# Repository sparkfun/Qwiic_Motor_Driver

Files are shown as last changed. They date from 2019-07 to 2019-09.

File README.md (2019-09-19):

SparkFun Qwiic_Motor_Driver
========================================

SparkFun Qwiic Motor Driver

[*SparkFun Qwiic Motor Driver (15451)*](https://www.sparkfun.com/products/15451)

The SparkFun Qwiic Motor Driver takes all the great features of the Serial Controlled Motor Driver (SCMD) and miniaturizes them, adding [Qwiic](https://www.sparkfun.com/qwiic) ports for plug and play functionality. Boasting the same 4245 PSOC and 2-channel motor ports as the SCMD, the SparkFun Qwiic Motor Driver is designed to communicate over I<sup>2</sup>C to make setting up your next robotic project as fast and easy as possible! Utilizing our handy Qwiic system, no soldering is required to connect it to the rest of your system. 

With 1.2A steady state drive per channel (1.5A peak) and 127 levels of DC drive strength, this little Qwiic board is perfect for your small DC motor driver needs. Since the Qwiic Motor Driver is a 3.3V logic device, you'll need to use a logic level converter to interface to 5V.

Repository Contents
-------------------

* **/Hardware** - Eagle design files (.brd, .sch)

Documentation
--------------
* **[Serial Controlled Motor Driver Library](https://github.com/sparkfun/SparkFun_Serial_Controlled_Motor_Driver_Arduino_Library)** - Arduino library for the Qwiic Motor Driver.
* **[Hookup Guide](https://learn.sparkfun.com/tutorials/hookup-guide-for-the-qwiic-motor-driver)** - Basic hookup guide for the Qwiic Motor Driver.

License Information
-------------------

This product is _**open source**_! 

Please review the LICENSE.md file for license information. 

If you have any questions or concerns on licensing, please contact technical support on our [SparkFun forums](https://forum.sparkfun.com/viewforum.php?f=152).

Distributed as-is; no warranty is given.

- Your friends at SparkFun.

_<COLLABORATION CREDIT>_

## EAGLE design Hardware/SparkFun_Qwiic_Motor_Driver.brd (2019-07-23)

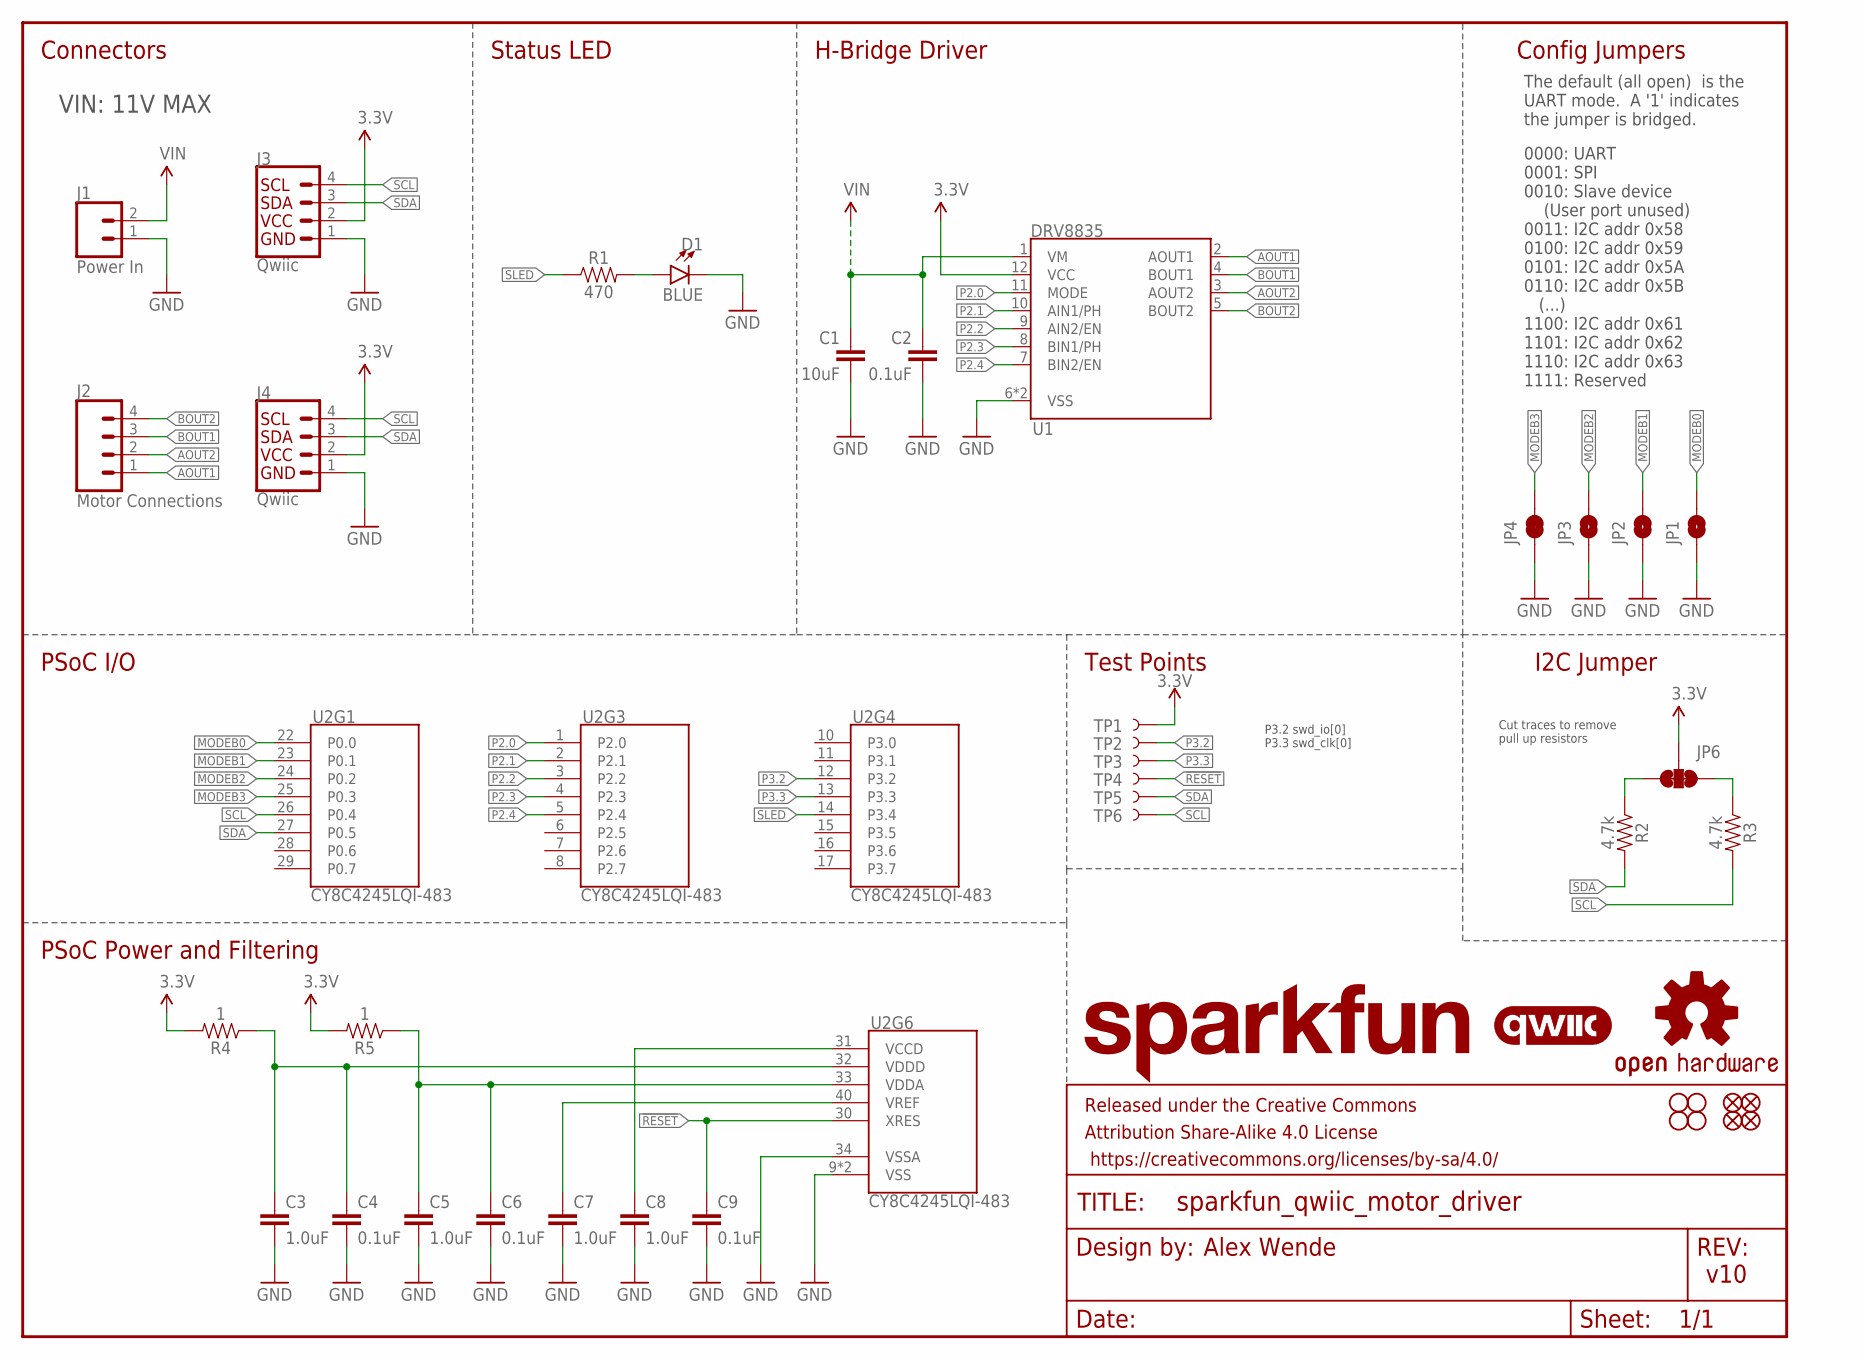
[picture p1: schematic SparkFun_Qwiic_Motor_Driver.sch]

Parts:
C1: 10uF; 0805
C2, C4, C6, C9: 0.1uF; 0402
C3, C5, C7, C8: 1.0uF; 0402
D1: BLUE; LED-0603
FD1, FD2, FD3, FD4: FIDUCIALUFIDUCIAL; FIDUCIAL-MICRO
FRAME1: FRAME-LETTER; CREATIVE_COMMONS
H1, H2, H3, H4: STAND-OFF
J1: Power In; SCREWTERMINAL-3.5MM-2
J2: Motor Connections; SCREWTERMINAL-3.5MM-4
J3, J4: Qwiic; JST04_1MM_RA
JP1, JP2, JP3: JUMPER-PAD-2; SMT-JUMPER_2_NO_NO-SILK
JP4: JUMPER-PAD-2; SMT-JUMPER_2_NC_TRACE_NO-SILK
JP6: JUMPER-SMT_3_2-NC_TRACE_NO-SILK; SMT-JUMPER_3_2-NC_TRACE_NO-SILK
LOGO2: OSHW-LOGOMINI; OSHW-LOGO-MINI
LOGO3: SFE_LOGO_NAME.1_INCH; SFE_LOGO_NAME_.1
R1: 470; 0603
R2, R3: 4.7k; 0603
R4, R5: 1; 0603
TP1, TP2, TP3, TP4, TP5, TP6: TEST-POINTTP_15TH_THRU; TP_15TH
U1: DRV8835; WSON-12
U2: CY8C4245LQI-483; QFN-40
U$1: QWIIC_LOGO_5MM; QWIIC_5MM

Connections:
3.3V: J3.2, J4.2, JP6.2, R4.2, R5.2, TP1.P$1, U1.12 (VCC)
!RESET: C9.1, TP4.P$1, U2.30 (XRES)
AOUT1: J2.1, U1.2 (AOUT1)
AOUT2: J2.2, U1.3 (AOUT2)
BOUT1: J2.3, U1.4 (BOUT1)
BOUT2: J2.4, U1.5 (BOUT2)
GND: C1.2, C2.2, C3.2, C4.2, C5.2, C6.2, C7.2, C8.2, C9.2, D1.C, J1.1, J3.1, J4.1, JP1.1, JP2.1, JP3.1, JP4.1, U1.6 (VSS), U1.PAD (VSS), U2.9 (VSS), U2.34 (VSSA), U2.EP (VSS)
MODEB0: JP1.2, U2.22 (P0.0)
MODEB1: JP2.2, U2.23 (P0.1)
MODEB2: JP3.2, U2.24 (P0.2)
MODEB3: JP4.2, U2.25 (P0.3)
unnamed: C8.1, U2.31 (VCCD)
unnamed: C5.1, C6.1, R5.1, U2.33 (VDDA)
unnamed: C7.1, U2.40 (VREF)
unnamed: D1.A, R1.2
unnamed: JP6.1, R3.1
unnamed: JP6.3, R2.1
P2.0: U1.11 (MODE), U2.1 (P2.0)
P2.1: U1.10 (AIN1/PH), U2.2 (P2.1)
P2.2: U1.9 (AIN2/EN), U2.3 (P2.2)
P2.3: U1.8 (BIN1/PH), U2.4 (P2.3)
P2.4: U1.7 (BIN2/EN), U2.5 (P2.4)
P3.2: TP2.P$1, U2.12 (P3.2)
P3.3: TP3.P$1, U2.13 (P3.3)
SCL: J3.4, J4.4, R3.2, TP6.P$1, U2.26 (P0.4)
SDA: J3.3, J4.3, R2.2, TP5.P$1, U2.27 (P0.5)
SLED: R1.1, U2.14 (P3.4)
VDDD: C3.1, C4.1, R4.1, U2.32 (VDDD)
VIN: C1.1, C2.1, J1.2, U1.1 (VM)

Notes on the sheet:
PSoC Power and Filtering
Config Jumpers
Alex Wende
PSoC I/O
v10
P3.2 swd_io[0] P3.3 swd_clk[0]
0000: UART 0001: SPI 0010: Slave device (User port unused) 0011: I2C addr 0x58 0100: I2C addr 0x59 0101: I2C addr 0x5A 0110: I2C addr 0x5B (...) 1100: I2C addr 0x61 1101: I2C addr 0x62 1110: I2C addr 0x63 1111: Reserved
The default (all open) is the UART mode. A '1' indicates the jumper is bridged.
Connectors
Status LED
H-Bridge Driver
Test Points
I2C Jumper
VIN: 11V MAX
Cut traces to remove pull up resistors

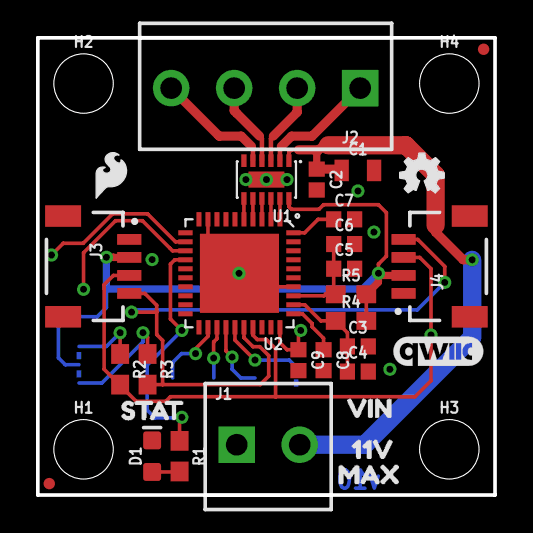
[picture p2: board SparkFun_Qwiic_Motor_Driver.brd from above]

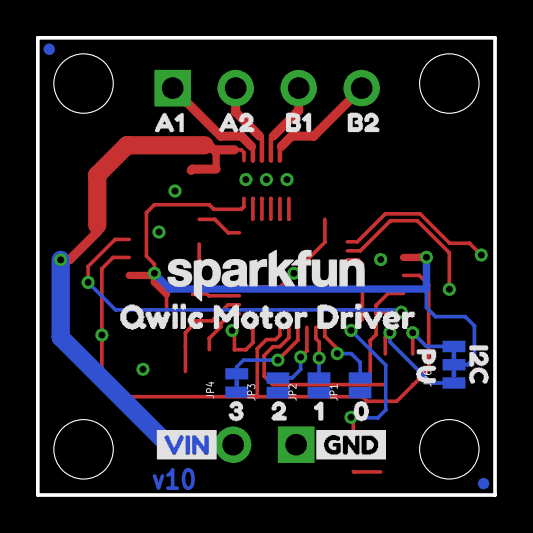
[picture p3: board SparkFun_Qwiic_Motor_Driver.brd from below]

Board: 2 copper layers, 25.4 x 25.4 mm, 62 parts (21 on the bottom side), 29 nets.

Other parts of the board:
U$2: STAT4
U$3: GND3
U$4: VIN2
U$5: 05
U$6: 16
U$7: 27
U$8: 38
U$9: A110
U$10: A211
U$11: B112
U$12: B213
U$13: 11V7
U$14: MAX8
U$15: VIN6
U$16: I2C0
U$17: PU1
U$18: QWIIC_MOTOR_DRIVER0
U$19: SFE_LOGO_FLAME_.1

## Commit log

2019-06-26 v01 Design Review Changes
    - Added I2C test points
    - Moved motor connector symbol to connection section
    - Changed status LED to blue
    - Adjusted VIN trace width
    - Added SFE flame to top side of board
    [SparkFun_Qwiic_Motor_Driver.brd, SparkFun_Qwiic_Motor_Driver.sch]
2019-07-22 v10 Update
    - Added new 4-pin screw terminal instead of 2x2-pin screw terminals
    - Added note about cutting traces to disable I2C pullup resistors
    [SparkFun_Qwiic_Motor_Driver.brd, SparkFun_Qwiic_Motor_Driver.sch]
2019-07-23 v10 QC changes
    Updated PROD_ID for the 4-pin screw terminal
    [SparkFun_Qwiic_Motor_Driver.brd, SparkFun_Qwiic_Motor_Driver.sch]
2019-09-03 Update SparkFun_Qwiic_Motor_Driver.sch
    Updated the config jumpers section of the schematic of valid addresses
    [SparkFun_Qwiic_Motor_Driver.sch]

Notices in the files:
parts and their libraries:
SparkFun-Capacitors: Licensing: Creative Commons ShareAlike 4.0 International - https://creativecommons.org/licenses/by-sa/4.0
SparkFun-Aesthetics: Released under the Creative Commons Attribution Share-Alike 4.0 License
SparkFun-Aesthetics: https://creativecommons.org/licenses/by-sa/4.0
